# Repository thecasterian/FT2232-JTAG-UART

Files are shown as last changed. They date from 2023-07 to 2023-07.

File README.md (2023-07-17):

# FT2232-JTAG-UART

## Introduction

This breakout board supports dual jtag/uart interface using FT2232H chip. Each of two ports can be configured as 4-wire JTAG (TCK, TDI, TDO, and TMS) or as UART (TXD and RXD).

The board is designed with KiCAD. The schematic and PCB layout are available in the subdirectories.
* [Rev. A](Rev.A)

## License

This project is licensed under the BSD 3-Clause License - see the [LICENSE](LICENSE) file for details.

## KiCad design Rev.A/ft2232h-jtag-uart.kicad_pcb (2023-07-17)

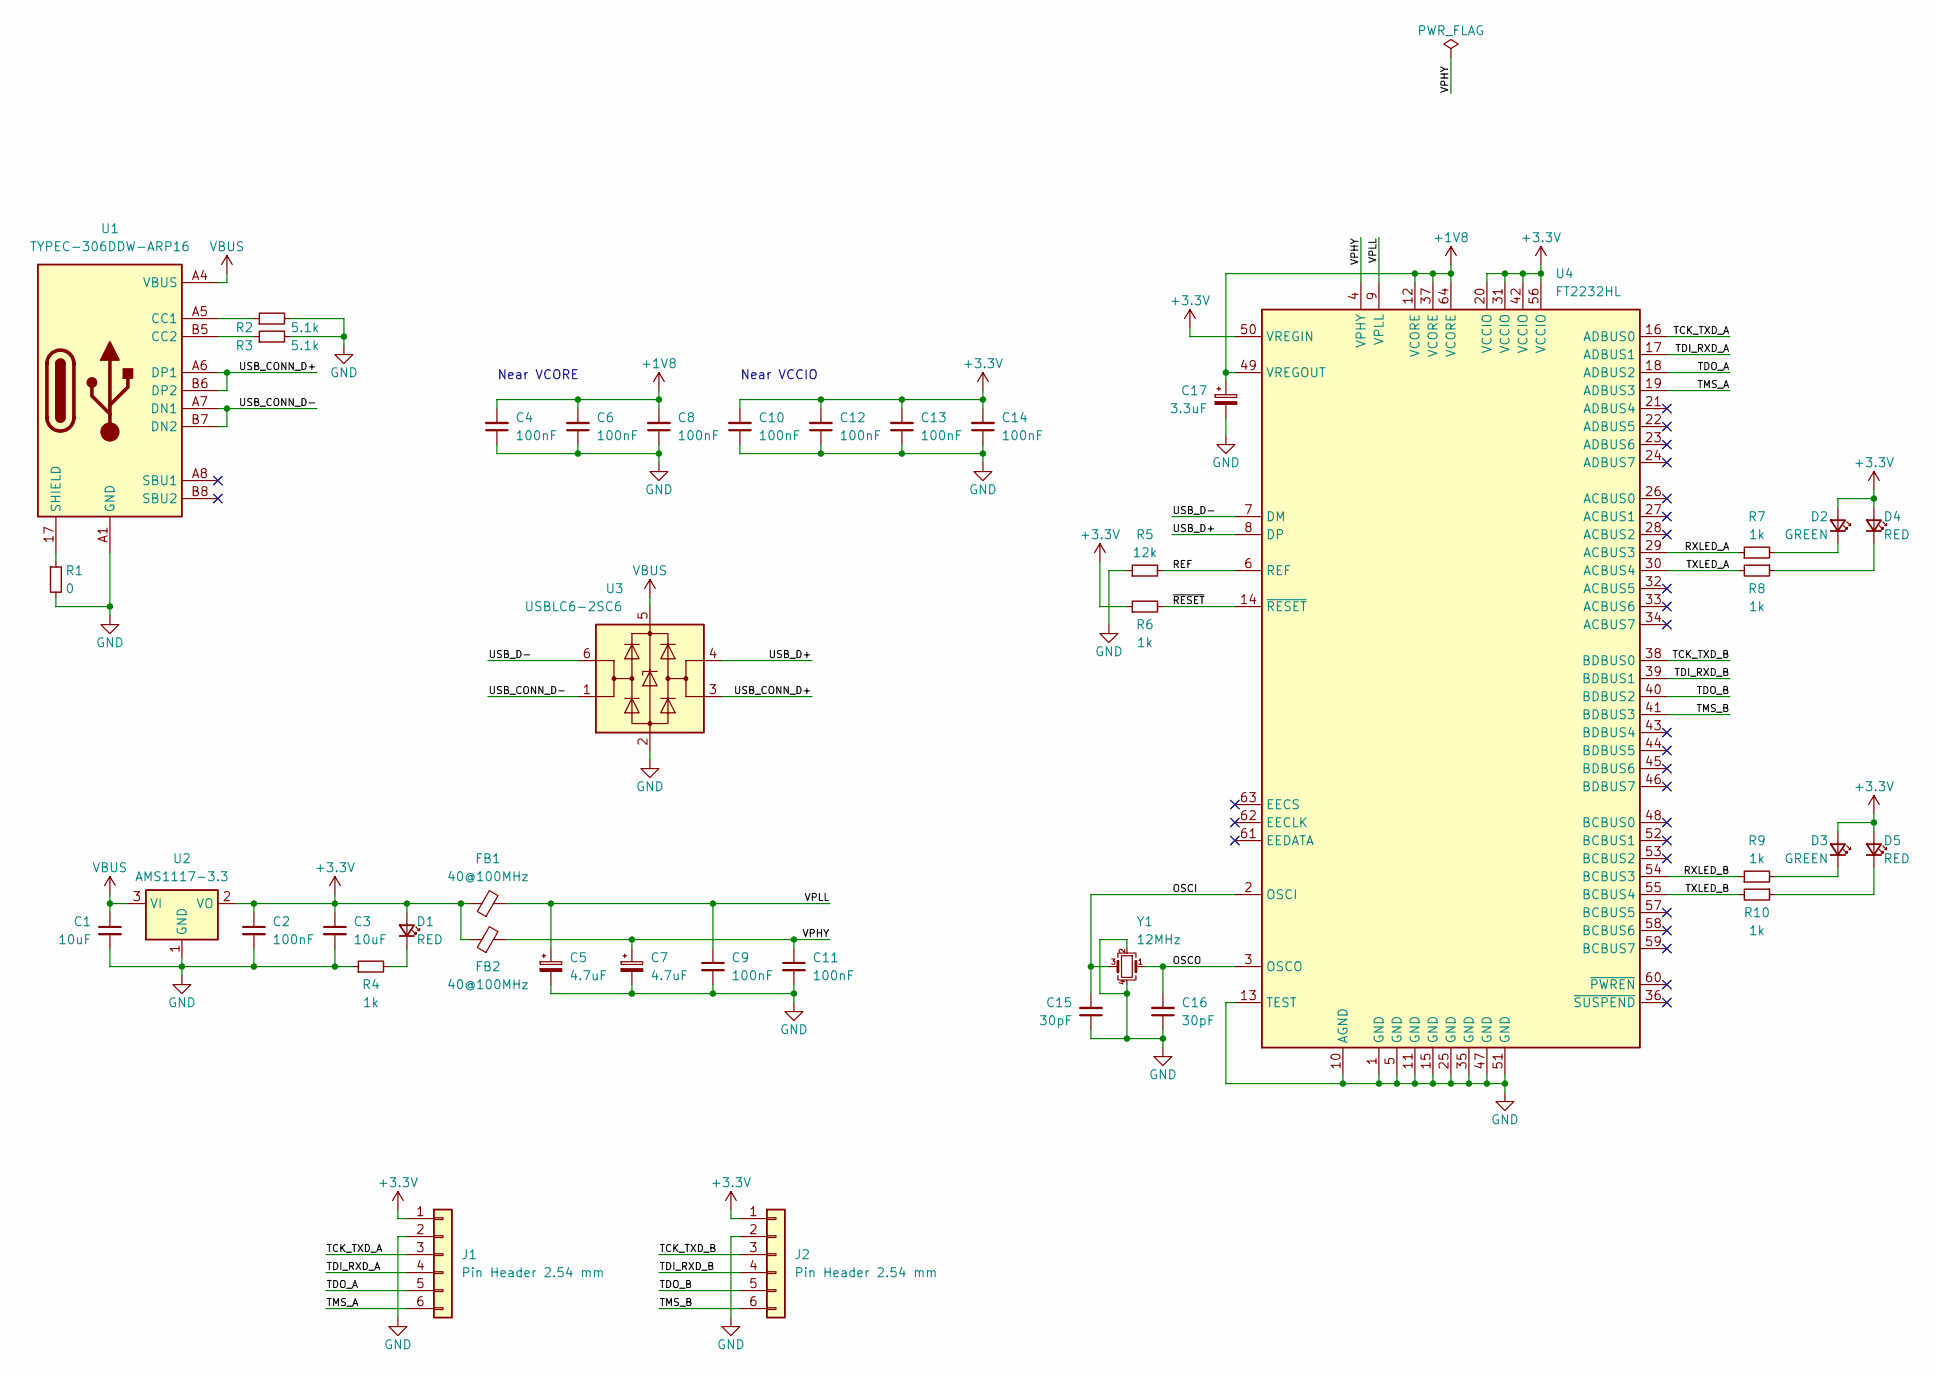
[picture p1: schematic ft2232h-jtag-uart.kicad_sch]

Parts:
C1, C3: 10uF; C_0603_1608Metric_Pad1.08x0.95mm_HandSolder; LCSC C19702
C2, C4, C6, C8, C9, C10, C11, C12, C13, C14: 100nF; C_0603_1608Metric_Pad1.08x0.95mm_HandSolder; LCSC C14663
C5, C7: 4.7uF; CP_EIA-3216-18_Kemet-A_Pad1.58x1.35mm_HandSolder; LCSC C1952741
C15, C16: 30pF; C_0603_1608Metric_Pad1.08x0.95mm_HandSolder; LCSC C1658
C17: 3.3uF; CP_EIA-3216-18_Kemet-A_Pad1.58x1.35mm_HandSolder; LCSC C1955444
D1, D4, D5: RED; LED_0603_1608Metric_Pad1.05x0.95mm_HandSolder; LCSC C2286
D2, D3: GREEN; LED_0603_1608Metric_Pad1.05x0.95mm_HandSolder; LCSC C72043
FB1, FB2: 40@100MHz; L_0603_1608Metric_Pad1.05x0.95mm_HandSolder; LCSC C142073
J1, J2: Pin Header 2.54 mm; PinHeader_1x06_P2.54mm_Vertical; LCSC C37208
R1: 0; R_0603_1608Metric_Pad0.98x0.95mm_HandSolder; LCSC C21189
R2, R3: 5.1k; R_0603_1608Metric_Pad0.98x0.95mm_HandSolder; LCSC C23186
R4, R6, R7, R8, R9, R10: 1k; R_0603_1608Metric_Pad0.98x0.95mm_HandSolder; LCSC C21190
R5: 12k; R_0603_1608Metric_Pad0.98x0.95mm_HandSolder; LCSC C22790
U1: TYPEC-306DDW-ARP16; USB-C-TH_TYPEC-306DDW-ARP16; LCSC C2840393
U2: AMS1117-3.3; SOT-223-3_TabPin2; LCSC C6186
U3: USBLC6-2SC6; SOT-23-6; LCSC C2827654
U4: FT2232HL; LQFP-64_10x10mm_P0.5mm; LCSC C27882
Y1: 12MHz; Crystal_SMD_3225-4Pin_3.2x2.5mm; LCSC C9002

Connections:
+1V8: C4.2, C6.2, C8.2, C17.1, U4.12 (VCORE), U4.37 (VCORE), U4.49 (VREGOUT), U4.64 (VCORE)
+3.3V: C2.1, C3.1, C10.2, C12.2, C13.2, C14.2, D1.2 (A), D2.2 (A), D3.2 (A), D4.2 (A), D5.2 (A), FB1.1, FB2.1, J1.1, J2.1, R6.1, U2.2 (VO), U4.20 (VCCIO), U4.31 (VCCIO), U4.42 (VCCIO), U4.50 (VREGIN), U4.56 (VCCIO)
/OSCI: C15.2, U4.2 (OSCI), Y1.3
/OSCO: C16.2, U4.3 (OSCO), Y1.1
/REF: R5.2, U4.6 (REF)
/RXLED_A: R7.1, U4.29 (ACBUS3)
/RXLED_B: R9.1, U4.54 (BCBUS3)
/TCK_TXD_A: J1.3, U4.16 (ADBUS0)
/TCK_TXD_B: J2.3, U4.38 (BDBUS0)
/TDI_RXD_A: J1.4, U4.17 (ADBUS1)
/TDI_RXD_B: J2.4, U4.39 (BDBUS1)
/TDO_A: J1.5, U4.18 (ADBUS2)
/TDO_B: J2.5, U4.40 (BDBUS2)
/TMS_A: J1.6, U4.19 (ADBUS3)
/TMS_B: J2.6, U4.41 (BDBUS3)
/TXLED_A: R8.2, U4.30 (ACBUS4)
/TXLED_B: R10.2, U4.55 (BCBUS4)
/USB_CONN_D+: U1.A6 (DP1), U1.B6 (DP2), U3.3 (I/O2)
/USB_CONN_D-: U1.A7 (DN1), U1.B7 (DN2), U3.1 (I/O1)
/USB_D+: U3.4 (I/O2), U4.8 (DP)
/USB_D-: U3.6 (I/O1), U4.7 (DM)
/VPHY: C7.1, C11.1, FB2.2, U4.4 (VPHY)
/VPLL: C5.1, C9.1, FB1.2, U4.9 (VPLL)
/~RESET: R6.2, U4.14 (~RESET)
GND: C1.2, C2.2, C3.2, C4.1, C5.2, C6.1, C7.2, C8.1, C9.2, C10.1, C11.2, C12.1, C13.1, C14.1, C15.1, C16.1, C17.2, J1.2, J2.2, R1.2, R2.2, R3.2, R4.1, R5.1, U1.A1 (GND), U1.A12 (GND), U1.B1 (GND), U1.B12 (GND), U2.1 (GND), U3.2 (GND), U4.1 (GND), U4.5 (GND), U4.10 (AGND), U4.11 (GND), U4.13 (TEST), U4.15 (GND), U4.25 (GND), U4.35 (GND), U4.47 (GND), U4.51 (GND), Y1.2, Y1.4
unnamed: D1.1 (K), R4.2
unnamed: D2.1 (K), R7.2
unnamed: D3.1 (K), R9.2
unnamed: D4.1 (K), R8.1
unnamed: D5.1 (K), R10.1
unnamed: R2.1, U1.A5 (CC1)
unnamed: R3.1, U1.B5 (CC2)
unnamed: R1.1, U1.17 (SHIELD), U1.18 (SHIELD), U1.19 (SHILED), U1.20 (SHIELD)
VBUS: C1.1, U1.A4 (VBUS), U1.A9 (VBUS), U1.B4 (VBUS), U1.B9 (VBUS), U2.3 (VI), U3.5 (VBUS)

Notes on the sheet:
Near VCORE
Near VCCIO

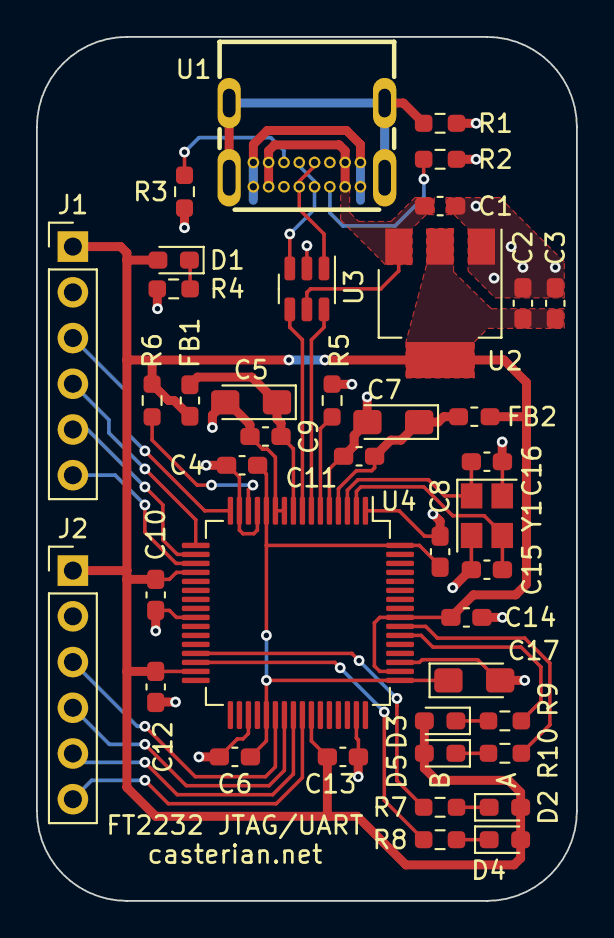
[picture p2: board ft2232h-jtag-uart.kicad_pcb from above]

Board: 2 copper layers, 30.0 x 48.0 mm, 41 parts (0 on the bottom side), 34 nets.
